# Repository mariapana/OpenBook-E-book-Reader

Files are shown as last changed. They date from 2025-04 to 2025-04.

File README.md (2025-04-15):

```
        .--.                   .---.
    .---|__|           .-.     |~~~|
.--|===|--|_          |_|     |~~~|--.
|  |===|  |'\     .---!~|  .--|   |--|		   ___                   ____              _    
|%%|   |  |.'\    |===| |--|%%|   |  |		  / _ \ _ __   ___ _ __ | __ )  ___   ___ | | __
|%%|   |  |\.'\   |   | |__|  |   |  |		 | | | | '_ \ / _ \ '_ \|  _ \ / _ \ / _ \| |/ /
|  |   |  | \  \  |===| |==|  |   |  |		 | |_| | |_) |  __/ | | | |_) | (_) | (_) |   < 
|  |   |__|  \.'\ |   |_|__|  |~~~|__|		  \___/| .__/ \___|_| |_|____/ \___/ \___/|_|\_\
|  |===|--|   \.'\|===|~|--|%%|~~~|--|		       |_|                                      
^--^---'--^    `-'`---^-^--^--^---'--'
```

## Table of Contents

1. [Block Diagram](#block-diagram)
2. [Bill of Materials (BOM)](#bill-of-materials-(bom))
3. [Components. Functionality. Measurements](#components-functionality-measurements)
4. [ESP32 C6 Pin Connections](#esp32-c6-pin-connections)
5. [Design Comments]()

## Block Diagram

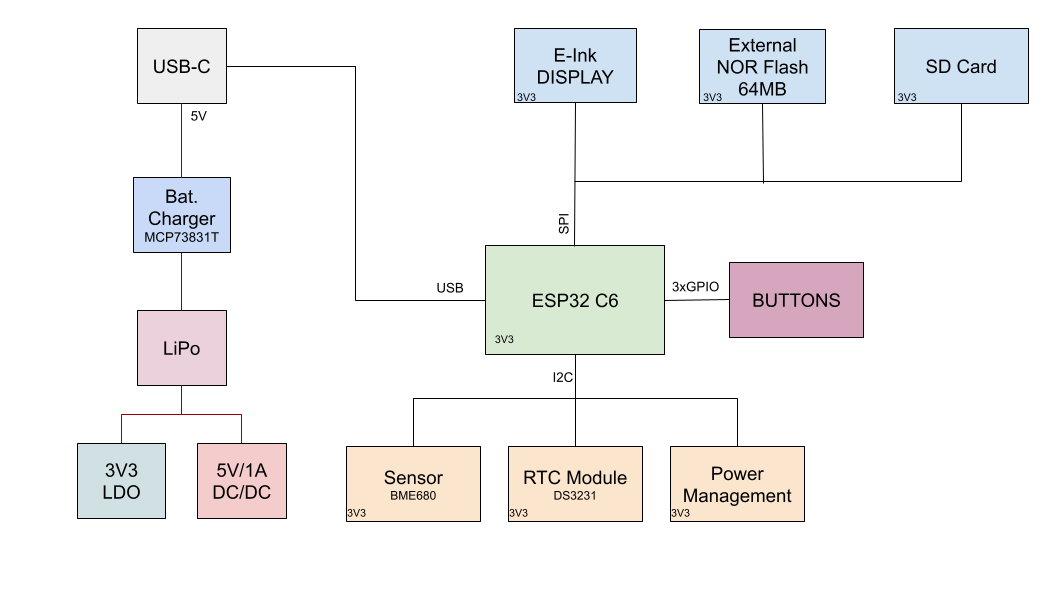
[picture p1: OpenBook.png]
Block Diagram


## Bill of Materials (BOM)

| Component | Link | Datasheet |
|---|---|---|
| Buttons (x3) | [Mouser](https://ro.mouser.com/ProductDetail/E-Switch/TL3315NF250Q?qs=g35H13458Kaz43%252B3owu1iQ%3D%3D) | [Datasheet](https://www.mouser.com/datasheet/2/140/TL3315-345930.pdf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)|
| BD5229G-TR | [Digikey](https://www.digikey.ee/en/models/658502) | [Datasheet](https://fscdn.rohm.com/en/products/databook/datasheet/ic/power/voltage_detector/bd52xxg-e.pdf)|
| CPH3225A | [SnapMagic](https://www.snapeda.com/parts/CPH3225A/Seiko+Instruments/view-part/?ref=eda) | [Datasheet](https://www.snapeda.com/parts/CPH3225A/Seiko%20Instruments/datasheet/) |
| Diode | [DigiKey](https://www.digikey.com/en/products/detail/littelfuse-inc/PGB1010603MR/715755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) | [Datasheet](https://www.littelfuse.com/assetdocs/pulseguard-esd-suppressors-pgb1-datasheet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) |
| Display Connector | [SnapMagic](https://www.snapeda.com/parts/FH34SRJ-24S-0.5SH(99)/Hirose/view-part/) | [Datasheet](https://ro.mouser.com/datasheet/2/185/FH34SRJ_24S_0_5SH_99__CL0580_1255_6_99_2DDrawing_0-1615044.pdf)|
| Environmental Sensor BME680 | [DigiKey](https://www.digikey.com/en/products/detail/bosch-sensortec/bme680/7401317) | [Datasheet](https://www.bosch-sensortec.com/media/boschsensortec/downloads/datasheets/bst-bme680-ds001.pdf)	|
| ESP32 C6 | [Mouser](https://ro.mouser.com/ProductDetail/Espressif-Systems/ESP32-C6-WROOM-1-N8?qs=8Wlm6%252BaMh8ST02Gmwp74cw%3D%3D) | [Datasheet](https://ro.mouser.com/datasheet/2/891/Espressif_ESP32_C6_WROOM_1__Datasheet_V0_1_PRELIMI-3239987.pdf)|
| External NOR Flash (64MB) | [Mouser](https://ro.mouser.com/ProductDetail/Winbond/W25Q512JVEIQ?qs=l7cgNqFNU1jw6svr3at6tA%3D%3D) | [Datasheet](https://ro.mouser.com/datasheet/2/949/Winbond_W25Q512JV_Datasheet-3240039.pdf)|
| Led | [GrabCAD](https://grabcad.com/library/0603-smd-led-1) | [Datasheet](https://www.snapeda.com/parts/KP-1608SURCK/Kingbright/datasheet/) |
| MAX17048G+T10	| [SnapMagic](https://www.snapeda.com/parts/MAX17048G+T10/Analog+Devices/view-part/?ref=eda) | [Datasheet](https://www.snapeda.com/parts/MAX17048G+T10/Analog%20Devices/datasheet/) |
| Li-Po Battery Charging Controller | [Mouser](https://ro.mouser.com/ProductDetail/Microchip-Technology/MCP73831T-3ACI-OT?qs=yUQqVecv4quInAWkk8YFWg%3D%3D) | [Datasheet](https://ro.mouser.com/datasheet/2/268/MCP73831_Family_Data_Sheet_DS20001984H-3441711.pdf)|
| LDO Regulator | [Mouser](https://ro.mouser.com/ProductDetail/Torex-Semiconductor/XC6220A331MR-G?qs=AsjdqWjXhJ8ZSWznL1J0gg%3D%3D) | [Datasheet](https://ro.mouser.com/datasheet/2/760/xc6220-3371556.pdf)|
| N-channel MOSFET | [DigiKey](https://www.digikey.ro/ro/products/detail/vishay-siliconix/SI1308EDL-T1-GE3/4876435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) | [Datasheet](https://www.vishay.com/docs/63399/si1308edl.pdf)|
| P-channel MOSFET | [DigiKey](https://www.digikey.com/en/products/detail/diodes-incorporated/DMG2305UX-7/4340667) | [Datasheet](https://www.diodes.com/assets/Datasheets/DMG2305UX.pdf) |
| PFMF.050.2 | [Mouser](https://eu.mouser.com/ProductDetail/Schurter/PFMF0502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) | [Datasheet](https://ro.mouser.com/datasheet/2/358/typ_PFMF-1275918.pdf) |
| Power Inductor | [Mouser](https://ro.mouser.com/ProductDetail/Bourns/SRR4828A-101M?qs=EU6FO9ffTwcw5i9FweW3JA%3D%3D) | [Datasheet](https://ro.mouser.com/datasheet/2/54/srr4828a-1391533.pdf)|
| Qwiic | [DigiKey](https://www.digikey.com/en/products/detail/onion-corporation/om-e-qwiic/9922970) | [Datasheet](https://cdn.sparkfun.com/assets/parts/1/2/2/8/9/Qwiic_Connector_Datasheet.pdf)|
| RCL CPOL 3528 | [DigiKey](https://www.snapeda.com/parts/TAJB475K025RNJ/AVX/view-part/?ref=dk&t=capacitor%203528&con_ref=None) | [Datasheet](https://s3.amazonaws.com/snapeda/datasheet/TAJB475K025RNJ_AVX.pdf) |
| Resistors | [Mouser](https://ro.mouser.com/c/?q=resistor%200402) | [Datasheet](https://ro.mouser.com/c/?q=resistor%200402)|
| Schottky Diodes | [Mouser](https://ro.mouser.com/ProductDetail/KYOCERA-AVX/SD0805S020S1R0?qs=jCA%252BPfw4LHbpkAoSnwrdjw%3D%3D) | [Datasheet](https://ro.mouser.com/datasheet/2/40/schottky-3165252.pdf)|
| SD Module | [Comet](https://store.comet.srl.ro/Catalogue/Product/43497/) | [Datasheet](https://store.comet.bg/download-file.php?id=8824)|
| SMC Diode | [DigiKey](https://www.digikey.ro/ro/products/detail/smc-diode-solutions/MBR0530/16692306) | [Datasheet](https://www.smc-diodes.com/propdf/MBR0530%20N0717%20REV.A.pdf)|
| Transistors | [Mouser](https://ro.mouser.com/ProductDetail/Diodes-Incorporated/DMG2305UX-7?qs=L1DZKBg7t5F%2FNBHrjfxC%252Bg%3D%3D) | [Datasheet](https://www.diodes.com/assets/Datasheets/DMG2305UX.pdf)|
| TP20R | [Mouser](https://eu.mouser.com/ProductDetail/Adafruit/3825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) | [Datasheet](https://cdn-shop.adafruit.com/product-files/3825/3825_diagram.PDF) |
| USB-C Connector | [Mouser](https://ro.mouser.com/ProductDetail/GCT/USB4110-GF-A?qs=KUoIvG%2F9IlYiZvIXQjyJeA%3D%3D) | [Datasheet](https://ro.mouser.com/datasheet/2/837/GCT_USB4110_Product_Drawing___20k_cycles-3455479.pdf)|
| USBLC6-2SC6Y | [Digikey](https://www.digikey.ro/ro/products/detail/stmicroelectronics/USBLC6-2SC6Y/2819177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) | [Datasheet](https://www.st.com/content/ccc/resource/technical/document/datasheet/group0/94/15/6c/58/ba/91/46/42/DM00055262/files/DM00055262.pdf/jcr:content/translations/en.DM000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)|

## Components. Functionality. Measurements

The system is built around an **ESP32 C6 microcontroller** featuring a RISC-V 32-bit architecture with integrated Wi-Fi 6 (802.11ax), Bluetooth 5 with Long Range support, and Zigbee/Thread capabilities for low-power mesh networking. Operating at 160 MHz with a 4-stage pipeline, it includes 320KB ROM, 528KB SRAM (512KB high-performance + 16KB low-power), and 30 GPIO pins. This central processor manages all communications, peripherals, and power consumption (160μA in deep sleep, 10mA active).

The visual interface is a **7.5-inch E-Paper (E-Ink) display** with 800×480 resolution, connected via SPI. This low-power display (1.2mW active, 0.1mW standby) maintains image visibility without power, making it ideal for battery-efficient applications. Key connections include MOSI, SCK, CS, DC, RST, and BUSY pins to the ESP32.

For environmental monitoring, a **BME688 multi-sensor** provides comprehensive measurements including:
- Gas detection (VOCs, CO, hydrogen)
- Humidity sensing (0-100% RH, ±3% accuracy)
- Temperature monitoring (-40°C to 85°C, ±0.5°C accuracy)
- Pressure detection (300-1100 hPa, ±0.6 hPa accuracy)

This I2C-connected sensor consumes approximately 3.6mA during measurements and just 0.1μA in sleep mode.

Power is supplied by a **3.7V 1800-2500mAh LiPo battery** (CELLEVIA LP584174) with USB-C charging capability. The system employs an **MCP73831T charging controller** for efficient battery management including precharge/fast charge modes, thermal regulation, and overvoltage protection. A dedicated **LDO voltage regulator** stabilizes the 3.3V supply for components, while a **voltage supervisor** monitors power levels and handles system resets when necessary.

The device features multiple storage options:
- **MicroSD card slot** (up to 32GB, FAT32) for e-books and user data, connected via SPI
- **64MB External NOR Flash** for firmware and critical system data
- **DS3231 RTC module** provides accurate timekeeping even during power loss, with battery backup and I2C connectivity

User input is facilitated through **three tactile push buttons** connected to GPIO pins for navigation and control functions. An **I2C-based QWIIC/Stemma QT connector** enables easy integration of additional modules and sensors.

The board includes comprehensive connectivity through:
- USB-C connector with ESD protection (PFMF varistor) and reverse polarity protection (Schottky barrier diode)
- Wi-Fi 6 and Bluetooth 5 wireless capabilities
- Various test pads for debugging and development

## ESP32 C6 Pin Connections

| Pin/Port | Connected To | Description |
|---|---|---|
| EN | RESET Button | Hardware reset button |
| IO0 | INT_RTC | Interrupt signal from RTC |
| IO1 | 32KHz | 32kHz clock signal input |
| IO2 | MISO | Master In Slave Out for SPI devices |
| IO3 | EPD_BUSY | E-Ink display busy status indicator |
| IO4 | SS_SD | Chip select for SD card |
| IO5 | EPD_DC | Data/Command control for E-Ink display |
| IO6 | SCK | SPI clock signal |
| IO7 | MOSI | Master Out Slave In for SPI devices |
| IO8 | 3V3 | 3.3V power supply |
| IO9 | BOOT Button | Boot mode selection button |
| IO10 | EPD_CS | Chip select for E-Ink display |
| IO11 | FLASH_CS | Chip select for external Flash memory |
| IO12 | USB_D- | USB data negative |
| IO13 | USB_D+ | USB data positive |
| IO15 | CHANGE Button | User action button |
| IO16/TXD0 | TX (UART) | UART transmit line |
| IO17/RXD0 | RX (UART) | UART receive line |
| IO18 | RTC_RST | Reset line for RTC module |
| IO19 | I2C_PW | Power control for I2C devices |
| IO20 | EPD_3V3_C | 3.3V power for E-Ink display |
| IO21 | SDA | I2C data line (BME688, DS3231, MAX17048) |
| IO22 | SCL | I2C clock line (BME688, DS3231, MAX17048) |
| IO23 | EPD_RST | Reset line for E-Ink display |
| 3V3 | Power Rail | 3.3V power distribution |
| GND | Ground | Common ground connection |

## Design Comments

While DRC throws two Board Outline Clearance errors, I have decided to keep the position of the J2 USB C Connector as is.
This is so that the component reaches the margin of the ebook reader and can be used by the client.

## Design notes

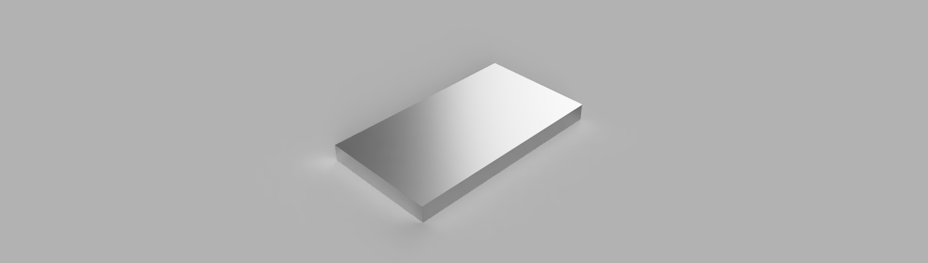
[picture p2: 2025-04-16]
Images/Battery.png

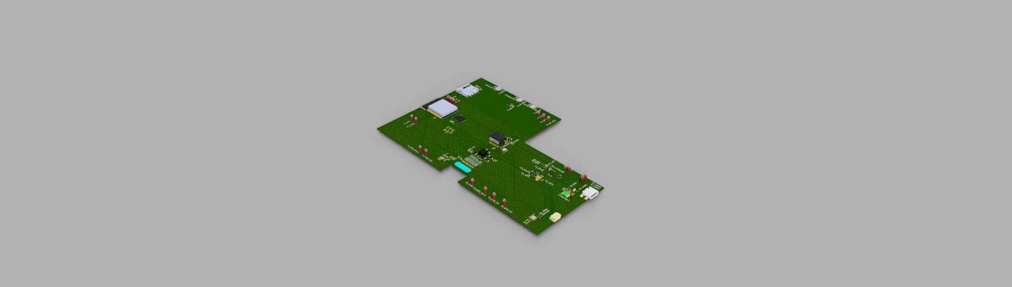
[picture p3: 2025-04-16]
Images/PCB.png

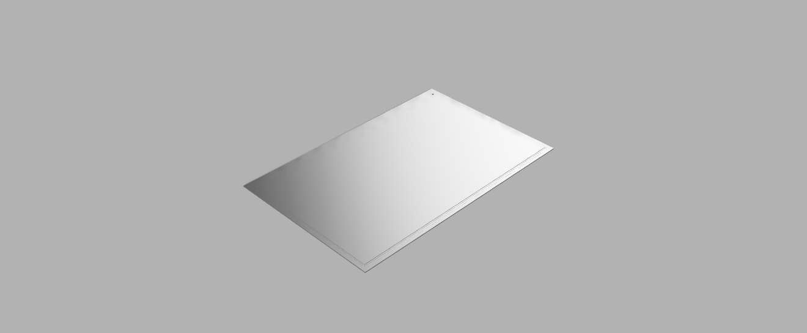
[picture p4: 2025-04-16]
Images/Display.png

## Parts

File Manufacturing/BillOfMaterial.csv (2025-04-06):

Qty | Value | Device | Package | Parts | Description | ARROW_PART_NUMBER | ARROW_PRICE-STOCK | AVAILABILITY | CENTROID_NOT_SPECIFIED | CHECK_PRICES | COPYRIGHT | DATASHEET | DESCRIPTION | DIGIKEY_DESCRIPTION | DIGIKEY_PART_NUMBER | HEIGHT | LEAD_FREE | MANUFACTURER_NAME | MANUFACTURER_PART_NUMBER | MF | MFR_NAME | MOUSER_PART_NUMBER | MOUSER_PRICE-STOCK | MOUSER_TESTING_PART_NUMBER | MOUSER_TESTING_PRICE-STOCK | MP | MPN | PACKAGE | POPULARITY | PREFIX | PRICE | PROD_ID | PURCHASE-URL | ROHS | SNAPEDA_LINK | SPICEMODEL | SPICEPREFIX | TEMPERATURE_RANGE_HIGH | TEMPERATURE_RANGE_LOW | TP_SIGNAL_NAME | VALUE
1 |  | ADAFRUIT_LEDCHIP-LED0603 | ADAFRUIT_CHIP-LED0603 | CHG_LED | LED
1 |  | ESP32C6_VARISTORCN1812 | ESP32C6_VARISTOR_CT/CN1812 | PFMF.050.1 | VARISTOR |  |  |  |  |  |  |  |  |  |  |  |  |  |  |  |  |  |  |  |  |  |  |  | 0
1 |  | SAMACSYS_PARTS_USB4110-GF-A | SAMACSYS_PARTS_USB4110GFA | J2 | CONN USB 2.0 TYPE-C R/A SMT |  |  |  |  |  |  |  | CONN USB 2.0 TYPE-C R/A SMT |  |  | 3.26mm |  | GCT (GLOBAL CONNECTOR TECHNOLOGY) | USB4110-GF-A |  |  | 640-USB4110-GF-A | https://www.mouser.co.uk/ProductDetail/GCT/USB4110-GF-A?qs=KUoIvG%2F9IlYiZvIXQjyJeA%3D%3D
1 |  | SJ | SJ | SJ1 | SMD solder JUMPER |  |  |  |  |  |  |  |  |  |  |  |  |  |  |  |  |  |  |  |  |  |  |  | 3
1 | 0.47 | ESP32_WROVER_EAGLE-LTSPICE_RR0402 | ESP32_WROVER_EAGLE-LTSPICE_R0402 | R3 | RESISTOR, European symbol |  |  |  |  |  |  |  |  |  |  |  |  |  |  |  |  |  |  |  |  |  |  |  |  |  |  |  |  |  |  | NONE | R
1 | 100k | ESP32_WROVER_EAGLE-LTSPICE_RR0402 | ESP32_WROVER_EAGLE-LTSPICE_R0402 | R1_PWRUSB | RESISTOR, European symbol |  |  |  |  |  |  |  |  |  |  |  |  |  |  |  |  |  |  |  |  |  |  |  |  |  |  |  |  |  |  | NONE | R
2 | 100nF | EAGLE-LTSPICE_CC0402 | EAGLE-LTSPICE_C0402 | C4_USB, C9 | CAPACITOR, European symbol |  |  |  |  |  |  |  |  |  |  |  |  |  |  |  |  |  |  |  |  |  |  |  |  |  |  |  |  |  |  | NONE | C
6 | 100nF | ESP32_WROVER_EAGLE-LTSPICE_CC0402 | ESP32_WROVER_EAGLE-LTSPICE_C0402 | C1, C2, C6, C8, C10, C_DELAY | CAPACITOR, European symbol |  |  |  |  |  |  |  |  |  |  |  |  |  |  |  |  |  |  |  |  |  |  |  |  |  |  |  |  |  |  | NONE | C
1 | 100uF TANT | RCL_CPOL-EUCT3528 | RCL_CT3528 | C3 | POLARIZED CAPACITOR, European symbol |  |  |  |  |  |  |  |  |  |  |  |  |  |  |  |  |  |  |  |  |  |  |  | 0 |  |  |  |  |  |  |  | C
16 | 10K | ESP32_WROVER_EAGLE-LTSPICE_RR0402 | ESP32_WROVER_EAGLE-LTSPICE_R0402 | R1, R1_PINH, R1_PINH1, R2-PINH, R2-PINH1, R4, R5, R6, R7, R8, R9, R10, R_BOOT, R_CHANGE, R_CL1, R_RESET | RESISTOR, European symbol |  |  |  |  |  |  |  |  |  |  |  |  |  |  |  |  |  |  |  |  |  |  |  |  |  |  |  |  |  |  | NONE | R
1 | 10uF | EAGLE-LTSPICE_CC0402 | EAGLE-LTSPICE_C0402 | C7 | CAPACITOR, European symbol |  |  |  |  |  |  |  |  |  |  |  |  |  |  |  |  |  |  |  |  |  |  |  |  |  |  |  |  |  |  | NONE | C
1 | 112A-TAAR-R03_ATTEND | 112A-TAAR-R03_ATTEND | 112ATAARR03ATTEND | J4 | Micro SD Card Socket, Push-Push Type, Top Mount, SMT, H=1.83mm, 10u |  |  |  |  |  |  |  | Micro SD Card Socket | Push-Push Type | Top Mount | SMT | H=1.83mm | 10u |  |  | 1.9mm |  | ATTEND | 112A-TAAR-R03 ATTEND
1 | 15 | ESP32_WROVER_EAGLE-LTSPICE_RR0402 | ESP32_WROVER_EAGLE-LTSPICE_R0402 | R_CAPACITOR | RESISTOR, European symbol |  |  |  |  |  |  |  |  |  |  |  |  |  |  |  |  |  |  |  |  |  |  |  |  |  |  |  |  |  |  | NONE | R
1 | 1uF | ESP32_WROVER_EAGLE-LTSPICE_CC0402 | ESP32_WROVER_EAGLE-LTSPICE_C0402 | C5 | CAPACITOR, European symbol |  |  |  |  |  |  |  |  |  |  |  |  |  |  |  |  |  |  |  |  |  |  |  |  |  |  |  |  |  |  | NONE | C
10 | 1uF/50V | ESP32_WROVER_EAGLE-LTSPICE_CC0402 | ESP32_WROVER_EAGLE-LTSPICE_C0402 | EPD_C1, EPD_C2, EPD_C5, EPD_C6, EPD_C7, EPD_C8, EPD_C9, EPD_C10, EPD_C11, EPD_C12 | CAPACITOR, European symbol |  |  |  |  |  |  |  |  |  |  |  |  |  |  |  |  |  |  |  |  |  |  |  |  |  |  |  |  |  |  | NONE | C
1 | 2.2 | ESP32_WROVER_EAGLE-LTSPICE_RR0402 | ESP32_WROVER_EAGLE-LTSPICE_R0402 | R2 | RESISTOR, European symbol |  |  |  |  |  |  |  |  |  |  |  |  |  |  |  |  |  |  |  |  |  |  |  |  |  |  |  |  |  |  | NONE | R
1 | 200 | ESP32_WROVER_EAGLE-LTSPICE_RR0402 | ESP32_WROVER_EAGLE-LTSPICE_R0402 | R1_BAT | RESISTOR, European symbol |  |  |  |  |  |  |  |  |  |  |  |  |  |  |  |  |  |  |  |  |  |  |  |  |  |  |  |  |  |  | NONE | R
2 | 20V/4.2A/52mO/1.4W | ESP32_WROVER_SPARKFUN-DISCRETESEMI_MOSFET_PCH-DMG2305UX-7 | ESP32_WROVER_SPARKFUN-DISCRETESEMI_SOT23-3 | Q1, Q2 | P-channel MOSFETs |  |  |  |  |  |  |  |  |  |  |  |  |  |  |  |  |  |  |  |  |  |  |  |  |  |  | TRAN-14388 |  |  |  |  |  |  |  |  | 20V/4.2A/52mO/1.4W
1 | 2K | ESP32_WROVER_EAGLE-LTSPICE_RR0402 | ESP32_WROVER_EAGLE-LTSPICE_R0402 | R2_BAT | RESISTOR, European symbol |  |  |  |  |  |  |  |  |  |  |  |  |  |  |  |  |  |  |  |  |  |  |  |  |  |  |  |  |  |  | NONE | R
5 | 4.7uF | EAGLE-LTSPICE_CC0402 | EAGLE-LTSPICE_C0402 | C1_BAT, C1_BAT1, C1_BAT2, C2_BAT, C5_USB | CAPACITOR, European symbol |  |  |  |  |  |  |  |  |  |  |  |  |  |  |  |  |  |  |  |  |  |  |  |  |  |  |  |  |  |  | NONE | C
1 | 4.7uF/25V | EAGLE-LTSPICE_CC0402 | EAGLE-LTSPICE_C0402 | C4 | CAPACITOR, European symbol |  |  |  |  |  |  |  |  |  |  |  |  |  |  |  |  |  |  |  |  |  |  |  |  |  |  |  |  |  |  | NONE | C
2 | 5k1 | ESP32_WROVER_EAGLE-LTSPICE_RR0402 | ESP32_WROVER_EAGLE-LTSPICE_R0402 | R2-USB, R2-USB1 | RESISTOR, European symbol |  |  |  |  |  |  |  |  |  |  |  |  |  |  |  |  |  |  |  |  |  |  |  |  |  |  |  |  |  |  | NONE | R
1 | 68uH | 744043680IND_4828-WE-TPC_WRE | IND_4828-WE-TPC_WRE | L1 |  |  |  |  |  |  | Copyright (C) 2024 Ultra Librarian. All rights reserved. |  |  |  |  |  |  |  | 744043680 |  | Wurth Electronics
1 | BD5229G-TR | BD5229G-TR | SOT95P280X125-5N | IC1 | Voltage Detector with Adjustable Delay Time: CMOS processes are utilized to develop high precision, low current consumption CMOS reset ICs that allow arbitrary setting of the delay time. The extensive lineup includes both Nch Open Drain and CMOS output types in a wide range of detection voltages (from 2.3V to 6.0V, in 0.1V steps), enabling selection of the ideal solution based on customer requirements. In addition, the entire series is of course both lead-free and RoHS-compliant. |  |  |  |  |  |  |  | Voltage Detector with Adjustable Delay Time: CMOS processes are utilized to develop high precision | low current consumption CMOS reset ICs that allow arbitrary setting of the delay time. The extensive lineup includes both Nch Open Drain and CMOS output types in a wide range of detection voltages (from 2.3V to 6.0V | in 0.1V steps) | enabling selection of the ideal solution based on customer requirements. In addition | the entire series is of course both lead-free and RoHS-compliant. |  |  | 1.25mm |  | ROHM Semiconductor | BD5229G-TR |  |  | 755-BD5229G-TR | https://www.mouser.co.uk/ProductDetail/ROHM-Semiconductor/BD5229G-TR?qs=4kLU8WoGk0vvnhrrYwdszw%3D%3D
3 | BUTTON_CUSYOMV1 | BUTTON_CUSYOMV1 | MYBUTTON | BOOT_BUTTON, CHANGE_BUTTON, RESET_BUTTON
1 | CPH3225A | CPH3225A | CAPCP3225X100N | C10_SUPERCAP | Cap 0.011F 3.3V 1210 Flat Check availability |  |  | Not in stock |  | https://www.snapeda.com/parts/CPH3225A/Seiko+Instruments/view-part/?ref=eda |  |  | 11 mF (EDLC) Supercapacitor 3.3 V 1210 (3225 Metric) - - |  |  |  |  |  |  | Seiko Instruments |  |  |  |  |  | CPH3225A |  | 1210 Seiko |  |  | None |  | https://www.snapeda.com/api/url_track_click_mouser/?unipart_id=562593&manufacturer=Seiko Instruments&part_name=CPH3225A&search_term=None |  | https://www.snapeda.com/parts/CPH3225A/Seiko+Instruments/view-part/?ref=snap
1 | DS3231SN# | DS3231SN# | SOIC127P1032X265-16N | U3 | Real Time Clock Serial 16-Pin SOIC W T/R Check availability |  |  | In Stock |  | https://www.snapeda.com/parts/DS3231SN%23/Analog+Devices/view-part/?ref=eda |  |  | Extremely Accurate I²C-Integrated RTC/TCXO/Crystal |  |  |  |  |  |  | Analog Devices |  |  |  |  |  | DS3231SN# |  | SOIC-16 Maxim |  |  | None |  | https://www.snapeda.com/api/url_track_click_mouser/?unipart_id=99048&manufacturer=Analog Devices&part_name=DS3231SN#&search_term=None |  | https://www.snapeda.com/parts/DS3231SN%23/Analog+Devices/view-part/?ref=snap
1 | ESP32-C6-WROOM-1-N8 | ESP32-C6-WROOM-1-N8 | XCVR_ESP32-C6-WROOM-1-N8 | U2 | Check availability |  |  | In Stock |  | https://www.snapeda.com/parts/ESP32-C6-WROOM-1-N8/Espressif+Systems/view-part/?ref=eda |  |  | Multiprotocol Modules ESP32-C6 module | Wi-Fi 6 in 2.4 GHz band | Bluetooth 5 | Zigbee 3.0 and Thread. ESP34-WROOM Compatible - ENGINEERING SAMPLE |  |  |  |  |  |  | Espressif Systems |  |  |  |  |  | ESP32-C6-WROOM-1-N8 |  | None |  |  | None |  |  |  | https://www.snapeda.com/parts/ESP32-C6-WROOM-1-N8/Espressif+Systems/view-part/?ref=snap
1 | ESP32_WROVER_AVX---SD0805S020S1R0_AVX_SD0805S020S1R0_0_0AVX_SD0805S020S1R0_0_0 | ESP32_WROVER_AVX---SD0805S020S1R0_AVX_SD0805S020S1R0_0_0AVX_SD0805S020S1R0_0_0 | ESP32_WROVER_AVX---SD0805S020S1R0_AVX_SD0805S020S1R0_0 | D7 | Schottky Barrier Rectifier Diode |  |  |  | No |  |  | http://datasheets.avx.com/schottky.pdf |  | DIODE SCHOTTKY 20V 1A 0805 | 478-7800-1-ND |  | yes |  |  | AVX |  | 581-SD0805S020S1R0 |  |  |  |  |  | 0805 (2012 metric) |  | D |  |  |  | yes |  |  |  | +125°C | -55°C
1 | ESP32_WROVER_BME680_BME680 | ESP32_WROVER_BME680_BME680 | ESP32_WROVER_BME680_PSON80P300X300X100-8N | SENSOR2 | Integrated Environmental Unit |  |  | Unavailable |  |  |  |  | Integrated Environmental Unit |  |  |  |  |  |  | Bosch Sensortec |  |  |  |  |  | BME680 |  | LGA-8 Bosch Tools |  |  | None
1 | ESP32_WROVER_SPARKFUN-IC-POWER_MCP73831 | ESP32_WROVER_SPARKFUN-IC-POWER_MCP73831 | ESP32_WROVER_SPARKFUN-IC-POWER_SOT23-5 | MCP73831 | MCP73831T Li-Ion, Li-Pol Controller |  |  |  |  |  |  |  |  |  |  |  |  |  |  |  |  |  |  |  |  |  |  |  |  |  |  | IC-09995
1 | FH34SRJ-24S-0.5SH_99_ | FH34SRJ-24S-0.5SH_99_ | FH34SRJ24S05SH99 | J1 | (0.50mm) Surface Mount, Right Angle |  |  |  |  |  |  |  | 24 Position FFC | FPC Connector Contacts | (0.50mm) Surface Mount | Right Angle |  |  | 1.1mm |  | Hirose | FH34SRJ-24S-0.5SH(99) |  |  | 798-FH34SRJ24S05SH99 | https://www.mouser.co.uk/ProductDetail/Hirose-Connector/FH34SRJ-24S-0.5SH99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
1 | MAX17048G+T10 | MAX17048G+T10 | SON50P200X200X80-9N | U4 | Check availability |  |  | In Stock |  | https://www.snapeda.com/parts/MAX17048G+T10/Analog+Devices/view-part/?ref=eda |  |  | 3µA 1-Cell/2-Cell Fuel Gauge with ModelGauge |  |  |  |  |  |  | Analog Devices |  |  |  |  |  | MAX17048G+T10 |  | TDFN-8 Maxim |  |  | None |  | https://www.snapeda.com/api/url_track_click_mouser/?unipart_id=329239&manufacturer=Analog Devices&part_name=MAX17048G+T10&search_term=None |  | https://www.snapeda.com/parts/MAX17048G+T10/Analog+Devices/view-part/?ref=snap
3 | MBR0530 | MBR0530 | SOD3716X135N | D3, D4, D5 | ON SEMICONDUCTOR - MBR0530 - DIODE, SCHOTTKY, 0.5A, 30V, SOD-123 |  |  | In Stock |  | https://www.snapeda.com/parts/MBR0530/Onsemi/view-part/?ref=eda |  |  | Diode Schottky 30 V 500mA Surface Mount SOD-123 |  |  |  |  |  |  | ON Semiconductor |  |  |  |  |  | MBR0530 |  | SOD-123-2 ON Semiconductor |  |  | None |  | https://www.snapeda.com/api/url_track_click_mouser/?unipart_id=179458&manufacturer=ON Semiconductor&part_name=MBR0530&search_term=None |  | https://www.snapeda.com/parts/MBR0530/Onsemi/view-part/?ref=snap
6 | PGB1010603MR | PGB1010603MR | DIOC1608X36N | D6, D8, D9, D10, D11, D12 | Check availability |  |  | In Stock |  | https://www.snapeda.com/parts/PGB1010603MR/Littelfuse/view-part/?ref=eda |  |  | 150V (Typ) Clamp - Ipp Tvs Diode Surface Mount 0603 (1608 Metric) |  |  |  |  |  |  | Littelfuse Inc. |  |  |  |  |  | PGB1010603MR |  | 0603 Littelfuse Inc. |  |  | None |  | https://www.snapeda.com/api/url_track_click_mouser/?unipart_id=5659453&manufacturer=Littelfuse Inc.&part_name=PGB1010603MR&search_term=None |  | https://www.snapeda.com/parts/PGB1010603MR/Littelfuse/view-part/?ref=snap
1 | QWIIC_RIGHT_ANGLE | QWIIC_CONNECTORJS-1MM | JST04_1MM_RA | J3 | SparkFun I2C Standard Qwiic Connector |  |  |  |  |  |  |  |  |  |  |  |  |  |  |  |  |  |  |  |  |  |  |  |  |  |  | CONN-13694 |  |  |  |  |  |  |  |  | QWIIC_RIGHT_ANGLE
1 | SD0805S020S1R0 | ESP32_WROVER_AVX---SD0805S020S1R0_AVX_SD0805S020S1R0_0_0AVX_SD0805S020S1R0_0_0 | ESP32_WROVER_AVX---SD0805S020S1R0_AVX_SD0805S020S1R0_0 | D2 | Schottky Barrier Rectifier Diode |  |  |  | No |  |  | http://datasheets.avx.com/schottky.pdf |  | DIODE SCHOTTKY 20V 1A 0805 | 478-7800-1-ND |  | yes |  |  | AVX |  | 581-SD0805S020S1R0 |  |  |  |  |  | 0805 (2012 metric) |  | D |  |  |  | yes |  |  |  | +125°C | -55°C
1 | SI1308EDL-T1-GE3 | SI1308EDL-T1-GE3 | SOT65P210X110-3N | Q3 | MOSFET N-Ch 30V 1.5A TrenchFET SC70 Vishay Si1308EDL-T1-GE3 N-channel MOSFET Transistor, 1.5 A, 30 V, 3-Pin SC-70 |  |  | In Stock |  | https://www.snapeda.com/parts/SI1308EDL-T1-GE3/Vishay+Siliconix/view-part/?ref=eda |  |  | Si1308EDL-T1-GE3 N-channel MOSFET Transistor | 1.5 A | 30 V | 3-Pin SC-70 | Siliconix / Vishay SI1308EDL-T1-GE3 |  |  |  |  |  |  | Vishay Siliconix |  |  |  |  |  | SI1308EDL-T1-GE3 |  | SOT-323 Vishay Semiconductor |  |  | None |  | https://www.snapeda.com/api/url_track_click_mouser/?unipart_id=274603&manufacturer=Vishay Siliconix&part_name=SI1308EDL-T1-GE3&search_term=None |  | https://www.snapeda.com/parts/SI1308EDL-T1-GE3/Vishay+Siliconix/view-part/?ref=snap
17 | TPTP20R | TPTP20R | TP20R | TP1, TP2, TP3, TP4, TP5, TP6, TP7, TP8, TP9, TP10, TP11, TP12, TP13, TP14, TP15, TP16, TP17 | Test pad |  |  |  |  |  |  |  |  |  |  |  |  |  |  |  |  |  |  |  |  |  |  |  | 2
1 | USBLC6-2SC6Y | USBLC6-2SC6Y | SOT95P280X145-6N | D1 | Low Cap. ESD Protection Auto SOT-23-6 STMicroelectronics USBLC6-2SC6Y, Dual Uni-Directional TVS Diode Array, 6-Pin SOT-23 |  |  | In Stock |  | https://www.snapeda.com/parts/USBLC6-2SC6Y/STMicroelectronics/view-part/?ref=eda |  |  | 17V Clamp 5A (8/20µs) Ipp Tvs Diode Surface Mount SOT-23-6 |  |  |  |  |  |  | STMicroelectronics |  |  |  |  |  | USBLC6-2SC6Y |  | SOT-23-6 STMicroelectronics |  |  | None |  |  |  | https://www.snapeda.com/parts/USBLC6-2SC6Y/STMicroelectronics/view-part/?ref=snap
1 | W25Q512JVEIQ | W25Q512JVEIQ | SON127P600X800X80-9N | U1 | Check availability |  |  | In Stock |  | https://www.snapeda.com/parts/W25Q512JVEIQ/Winbond+Electronics/view-part/?ref=eda |  |  | FLASH - NOR Memory IC 512Mb (64M x 8) SPI - Quad I/O 133 MHz 8-WSON (8x6) |  |  |  |  |  |  | Winbond Electronics |  |  |  |  |  | W25Q512JVEIQ |  | Package |  |  | None |  |  |  | https://www.snapeda.com/parts/W25Q512JVEIQ/Winbond+Electronics/view-part/?ref=snap
1 | XC6220A331MR-G | XC6220A331MR-G | SOT95P280X120-5N | IC4 | LDO Voltage Regulators |  |  |  |  |  |  |  | LDO Voltage Regulators |  |  | 1.2mm |  | Torex | XC6220A331MR-G |  |  | 865-XC6220A331MR-G | https://www.mouser.co.uk/ProductDetail/Torex-Semiconductor/XC6220A331MR-G?qs=AsjdqWjXhJ8ZSWznL1J0gg%3D%3D

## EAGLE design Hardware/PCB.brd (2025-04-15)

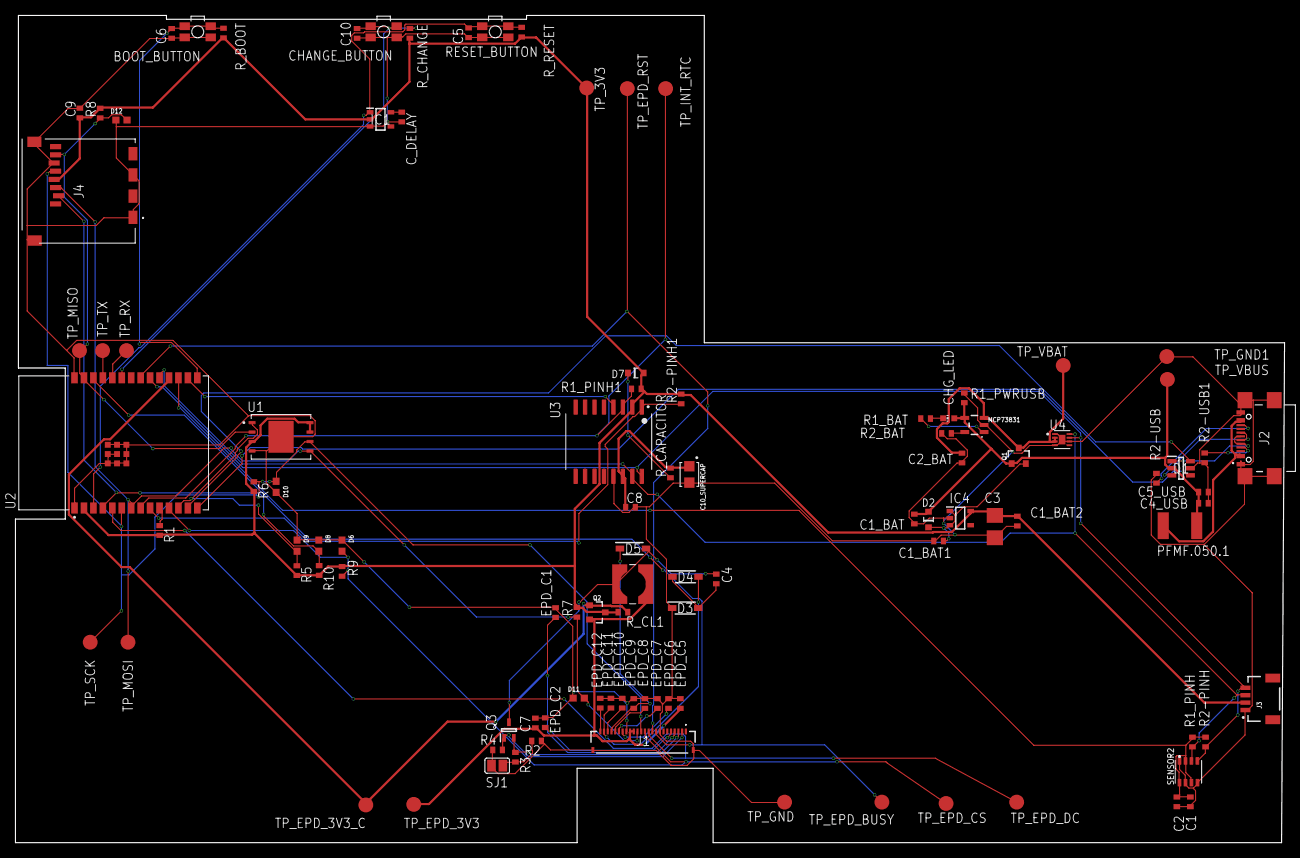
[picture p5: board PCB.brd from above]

Board: 2 copper layers, 170.6 x 111.2 mm, 103 parts (0 on the bottom side), 55 nets.

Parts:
BOOT_BUTTON: BUTTON_CUSYOMV1; MYBUTTON
C1, C2, C4_USB, C6, C8, C9, C10: 100nF; EAGLE-LTSPICE_C0402
C1_BAT, C1_BAT1, C1_BAT2, C2_BAT, C5_USB: 4.7uF; EAGLE-LTSPICE_C0402
C3: 100uF TANT; RCL_CT3528
C4: 4.7uF/25V; EAGLE-LTSPICE_C0402
C5: 1uF; EAGLE-LTSPICE_C0402
C7: 10uF; EAGLE-LTSPICE_C0402
C10_SUPERCAP: CPH3225A; CAPCP3225X100N
CHANGE_BUTTON: BUTTON_CUSYOMV1; MYBUTTON
CHG_LED: ADAFRUIT_CHIP-LED0603
C_DELAY: 100nF; EAGLE-LTSPICE_C0402
D1: USBLC6-2SC6Y; SOT95P280X145-6N
D2: SD0805S020S1R0; ESP32_WROVER_AVX---SD0805S020S1R0_AVX_SD0805S020S1R0_0
D3, D4, D5: MBR0530; SOD3716X135N
D6, D8, D9, D10, D11, D12: PGB1010603MR; DIOC1608X36N
D7: ESP32_WROVER_AVX---SD0805S020S1R0_AVX_SD0805S020S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; ESP32_WROVER_AVX---SD0805S020S1R0_AVX_SD0805S020S1R0_0
EPD_C1, EPD_C2, EPD_C5, EPD_C6, EPD_C7, EPD_C8, EPD_C9, EPD_C10, EPD_C11, EPD_C12: 1uF/50V; EAGLE-LTSPICE_C0402
IC1: BD5229G-TR; SOT95P280X125-5N
IC4: XC6220A331MR-G; SOT95P280X120-5N
J1: FH34SRJ-24S-0.5SH_99_; FH34SRJ24S05SH99
J2: SAMACSYS_PARTS_USB4110-GF-A; SAMACSYS_PARTS_USB4110GFA
J3: QWIIC_RIGHT_ANGLE; JST04_1MM_RA
J4: 112A-TAAR-R03_ATTEND; 112ATAARR03ATTEND
L1: 68uH; IND_4828-WE-TPC_WRE
MCP73831: ESP32_WROVER_SPARKFUN-IC-POWER_MCP73831; ESP32_WROVER_SPARKFUN-IC-POWER_SOT23-5
PFMF.050.1: ESP32C6_VARISTOR_CT/CN1812
Q1, Q2: 20V/4.2A/52mΩ/1.4W; ESP32_WROVER_SPARKFUN-DISCRETESEMI_SOT23-3
Q3: SI1308EDL-T1-GE3; SOT65P210X110-3N
R1, R1_PINH, R1_PINH1, R2-PINH, R2-PINH1, R4, R5, R6, R7, R8, R9, R10: 10K; ESP32_WROVER_EAGLE-LTSPICE_R0402
R1_BAT: 200; ESP32_WROVER_EAGLE-LTSPICE_R0402
R1_PWRUSB: 100k; ESP32_WROVER_EAGLE-LTSPICE_R0402
R2: 2.2; ESP32_WROVER_EAGLE-LTSPICE_R0402
R2-USB, R2-USB1: 5k1; ESP32_WROVER_EAGLE-LTSPICE_R0402
R2_BAT: 2K; ESP32_WROVER_EAGLE-LTSPICE_R0402
R3: 0.47; ESP32_WROVER_EAGLE-LTSPICE_R0402
RESET_BUTTON: BUTTON_CUSYOMV1; MYBUTTON
R_BOOT: 10K; ESP32_WROVER_EAGLE-LTSPICE_R0402
R_CAPACITOR: 15; ESP32_WROVER_EAGLE-LTSPICE_R0402
R_CHANGE: 10K; ESP32_WROVER_EAGLE-LTSPICE_R0402
R_CL1: 10K; ESP32_WROVER_EAGLE-LTSPICE_R0402
R_RESET: 10K; ESP32_WROVER_EAGLE-LTSPICE_R0402
SENSOR2: ESP32_WROVER_BME680_BME680; ESP32_WROVER_BME680_PSON80P300X300X100-8N
SJ1: SJ
TP_3V3: TPTP20R; TP20R
TP_EPD_3V3, TP_EPD_3V3_C: TPTP20R; TP20R
TP_EPD_BUSY: TPTP20R; TP20R
TP_EPD_CS: TPTP20R; TP20R
TP_EPD_DC: TPTP20R; TP20R
TP_EPD_RST: TPTP20R; TP20R
TP_GND, TP_GND1: TPTP20R; TP20R
TP_INT_RTC: TPTP20R; TP20R
TP_MISO: TPTP20R; TP20R
TP_MOSI: TPTP20R; TP20R
TP_RX: TPTP20R; TP20R
TP_SCK: TPTP20R; TP20R
TP_TX: TPTP20R; TP20R
TP_VBAT: TPTP20R; TP20R
TP_VBUS: TPTP20R; TP20R
U1: W25Q512JVEIQ; SON127P600X800X80-9N
U2: ESP32-C6-WROOM-1-N8; XCVR_ESP32-C6-WROOM-1-N8
U3: DS3231SN#; SOIC127P1032X265-16N
U4: MAX17048G+T10; SON50P200X200X80-9N

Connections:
3V3: C1_BAT2.1, C3.+, C9.1, D7.2, IC1.2, IC4.5, J3.2, J4.P4, Q2.3, R1.2, R1_PINH1.2, R2-PINH1.2, R5.2, R6.2, R7.2, R8.2, R9.2, R10.2, R_BOOT.2, R_CHANGE.2, R_CL1.2, R_RESET.2, TP_3V3.TP, U1.3, U1.7, U1.8, U2.2, U3.2
32KHZ: R2-PINH1.1, U2.9, U3.1
DN: D1.1, J2.A7, J2.B7
DP: D1.3, J2.A6, J2.B6
EPD_3V3: C7.1, EPD_C5.1, J1.15, J1.16, L1.2, Q2.2, TP_EPD_3V3.TP
EPD_3V3_C: Q2.1, R_CL1.1, TP_EPD_3V3_C.TP, U2.18
EPD_BUSY: J1.9, TP_EPD_BUSY.TP, U2.26
EPD_CS: D6.2, J1.12, R9.1, TP_EPD_CS.TP, U2.11
EPD_DC: J1.11, TP_EPD_DC.TP, U2.5
EPD_RST: J1.10, TP_EPD_RST.TP, U2.21
FLASH_CS: D9.2, R5.1, U1.1, U2.12
GDR: J1.2, Q3.1, R4.2
GND: BOOT_BUTTON.1, BOOT_BUTTON.2, C1.2, C1_BAT.2, C1_BAT1.2, C1_BAT2.2, C2.2, C2_BAT.2, C3.-, C4_USB.2, C5.2, C5_USB.2, C6.2, C7.2, C8.2, C9.2, C10.2, C10_SUPERCAP.2, CHANGE_BUTTON.1, CHANGE_BUTTON.2, C_DELAY.2, D1.5, D3.1, D6.1, D8.1, D9.1, D10.1, D11.1, D12.1, EPD_C1.2, EPD_C2.2, EPD_C5.2, EPD_C6.2, EPD_C7.2, EPD_C8.2, EPD_C9.2, EPD_C10.2, EPD_C11.2, EPD_C12.2, IC1.3, IC4.2, J1.8, J1.17, J1.MP1, J1.MP2, J2.A1, J2.A12, J2.B1, J2.B12, J2.MP1, J2.MP2, J2.MP3, J2.MP4, J3.1, J4.G1, J4.G2, J4.G3, J4.G4, J4.P6, MCP73831.2, R1_PWRUSB.1, R2.1, R2-USB.2, R2-USB1.1, R2_BAT.1, R4.1, RESET_BUTTON.1, RESET_BUTTON.2, SENSOR2.1, SENSOR2.5, SENSOR2.7, SJ1.1, TP_GND.TP, TP_GND1.TP, U1.4, U1.9, U2.1, U2.28, U2.29_1, U2.29_2, U2.29_3, U2.29_4, U2.29_5, U2.29_6, U2.29_7, U2.29_8, U2.29_9, U3.13, U4.1, U4.4, U4.6, U4.9
GPIO8: R1.1, U2.10
I2C_PW: C1.1, C2.1, R1_PINH.2, R2-PINH.2, SENSOR2.2, SENSOR2.6, SENSOR2.8, U2.17
INT_RTC: R1_PINH1.1, TP_INT_RTC.TP, U2.8, U3.3
IO/BOOT: BOOT_BUTTON.3, BOOT_BUTTON.4, C6.1, R_BOOT.1, U2.15
IO/CHANGE: C10.1, CHANGE_BUTTON.3, CHANGE_BUTTON.4, R_CHANGE.1, U2.23
MISO: D12.2, J4.P7, R8.1, TP_MISO.TP, U1.2, U2.27
MOSI: D11.2, J1.14, J4.P3, R7.1, TP_MOSI.TP, U1.5, U2.7
unnamed: J2.A5, R2-USB1.2
unnamed: J2.B5, R2-USB.1
unnamed: C1_BAT1.1, D2.1, IC4.1, IC4.3, Q1.2
unnamed: C4.1, D3.2, D4.1
unnamed: EPD_C12.1, J1.24
unnamed: CHG_LED.C, R1_BAT.1
unnamed: MCP73831.1, R1_BAT.2
unnamed: MCP73831.5, R2_BAT.2
unnamed: C_DELAY.1, IC1.5
unnamed: EPD_C10.1, J1.22
unnamed: D7.1, R_CAPACITOR.1
unnamed: EPD_C8.1, J1.20
unnamed: EPD_C7.1, J1.19
unnamed: EPD_C6.1, J1.18
unnamed: EPD_C1.1, J1.4
unnamed: EPD_C2.1, J1.5
PREVGH: D5.1, EPD_C9.1, J1.21
PREVGL: D4.2, EPD_C11.1, J1.23
RESE: J1.3, Q3.2, R3.2
RESE': R2.2, R3.1, SJ1.2
RESET: C5.1, IC1.1, RESET_BUTTON.3, RESET_BUTTON.4, R_RESET.1, U2.3
RTC_RST: U2.16, U3.4
RX: TP_RX.TP, U2.24
SCK: D10.2, J1.13, J4.P5, R6.1, TP_SCK.TP, U1.6, U2.6
SCL: J3.4, R2-PINH.1, SENSOR2.4, U2.20, U3.16, U4.7
SDA: J3.3, R1_PINH.1, SENSOR2.3, U2.19, U3.15, U4.8
SRC: C4.2, D5.2, L1.1, Q3.3
SS_SD: D8.2, J4.P2, R10.1, U2.4
TX: TP_TX.TP, U2.25
USB_D+: D1.4, U2.14
USB_D-: D1.6, U2.13
VBAT: C2_BAT.1, MCP73831.3, Q1.3, TP_VBAT.TP, U4.2, U4.3
VBUS: C1_BAT.1, C4_USB.1, C5_USB.1, CHG_LED.A, D1.2, D2.2, MCP73831.4, PFMF.050.1.2, Q1.1, R1_PWRUSB.2, TP_VBUS.TP
VRTC: C8.1, C10_SUPERCAP.1, R_CAPACITOR.2, U3.14
VUSB: J2.A4, J2.A9, J2.B4, J2.B9, PFMF.050.1.1

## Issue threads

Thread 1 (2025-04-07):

Corectare diagrama bloc in README

raducosminalexandru, 2025-04-07:
Ar fi de preferat sa folosesti alta culoare intre conexiuni si nu negru, pentru ca nu se vad clar cum se conecteaza, mai ales protocoalele de comunicatie intre fiecare componente (I2C, UART etc.), pe fiecare conexiune, conform diagramei bloc data ca model.

Closed 2025-04-07.

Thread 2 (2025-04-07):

Decupare PCB

raducosminalexandru, 2025-04-07:
PCB-ul trebuie decupat sub antena modulului ESP32 pentru a evita interferentele cu semnalul radio.

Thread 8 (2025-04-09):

DRC - Component Exclude Clearance

mariapana, 2025-04-09:
Unele componente sunt prea apropiate pe PCB, producand eroarea Component Exclude Clearance la DRC. Este suficient sa distantezi EPD_C12 de EPD_C10.

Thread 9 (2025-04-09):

DRC - Air Wire

mariapana, 2025-04-09:
Conform verificarii DRC, exista mai multe erori de tip Air Wire din cauza unor trasee nerutate. Incearca sa minimizezi numarul lor folosind Autorouter sau realizand trasarea manual.

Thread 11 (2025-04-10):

Lipsa modele 3D componente

raducosminalexandru, 2025-04-10:
Nu ai modele 3D pentru componente. Descarca fiecare model pentru fiecare componenta de pe PCB de la sursa pusa si in cerinta proiectului.
Link recomandat: https://componentsearchengine.com/

Closed 2025-04-15.

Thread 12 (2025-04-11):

Lipsa nume 'Test Pads'

raducosminalexandru, 2025-04-11:
Trebuie numite exact ca in schematic, pentru a fi mai usor de inteles ce face fiecare, conform regulilor de creare a unui silkscreen bun (TP1 va fi numit TX spre exemplu, conform semnalului asociat).

Closed 2025-04-14.

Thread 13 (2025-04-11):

Erori DRC - Copper Width

raducosminalexandru, 2025-04-11:
Incearca sa intri in **footprint** la fiecarei componenta de are aceasta eroare si sa modifici marimea pinului problematic, pentru ca tu rutezi un cablu de 0.3mm intr-un pin mai mic de atat.

Closed 2025-04-14.

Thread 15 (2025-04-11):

Lipsa model 3D display

raducosminalexandru, 2025-04-11:
Realizeaza modelul 3D al display-ului conform urmatoarelor specificatii:

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

Ce te-ar interesa pe tine aici este 'Outline dimension', respecta acele restrictii.

raducosminalexandru, 2025-04-11:
Pentru a intelege cum faci acest model, recomand sa te uiti la #14, ai acolo un mic tutorial care te poate ajuta cum sa il realizezi.

Closed 2025-04-15.

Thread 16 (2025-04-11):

Grosime prea mare PCB 2D

raducosminalexandru, 2025-04-11:
Grosimea ar trebui sa fie 1mm, automat ea este pe 1.6mm, lucru care iti ingreuneaza bagarea in carcasa a PCB-ului.
Pentru a modifica, intra in schema din board (schema PCB 2D), apoi **Rules -> Preferences -> Layer Stack**

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

O sa ajungi intr-un meniu, bifezi optiunea **_Edit material properties_** si la **_Dielectric-1_** setezi 1mm in loc de 1.6mm.

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

Closed 2025-04-14.

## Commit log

2025-04-06 Commit HW
    [PCB.brd, Schematic.sch]
2025-04-06 Add Manufacturing/
    [BillOfMaterial.csv, PnP_PCB v23_front.csv]
2025-04-14 Fix #16
    [PCB.brd]
2025-04-14 Fix #2
    [PCB.brd]
2025-04-14 Fix #12
    [PCB.brd]
2025-04-14 Fix #13
    [PCB.brd]
2025-04-14 Fix #3, Fix #4
    [PCB.brd]
2025-04-15 Fix #5, Fix #11
    [PCB.brd]
2025-04-15 Fix #14
    [Battery.step]
2025-04-15 Fix #15
    [Display.step]
2025-04-16 Add full product model
    [Battery.step, Display.step]
2025-04-16 Add rendered PCB image
2025-04-16 Add rendered Battery image

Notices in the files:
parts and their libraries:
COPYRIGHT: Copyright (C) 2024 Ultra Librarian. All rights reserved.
